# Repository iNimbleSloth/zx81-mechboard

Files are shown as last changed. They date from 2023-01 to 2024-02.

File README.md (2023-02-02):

# ZX81-mechboard
Mechanical keyboard for the ZX81 plus 38 (https://github.com/mahjongg2/ZX81plus38)

This keyboard is designed to use Cherry MX or Gateron switches. <br>
The keyboard is open source, please feel free to modiy it but always link back to this repository.<br>

Watch my video series that features this keyboard on [YouTube](https://www.youtube.com/watch?v=6a8wxj9vJjU&list=PLx7VS_ZJdQyVQSyDkv-Idc9wqWm_9QVhM)<br><br>
KiCAD files_v1.1 - Schematic and PCB layout files for KiCAD<br>
keycaps layout - Keycaps design layout for Adobe Illustrator. Note that if useing wasdkeyboards, then you nned to use the expanded file.<br><br>
Available on [PCBWay Shared Projects](https://www.pcbway.com/project/shareproject/ZX81_Mechanical_Keyboard_68c46a1b.html)<br>

<br><br>
Keycaps printed by wasdkeyboards.com


<br>
Keycaps with sticky labels<br>


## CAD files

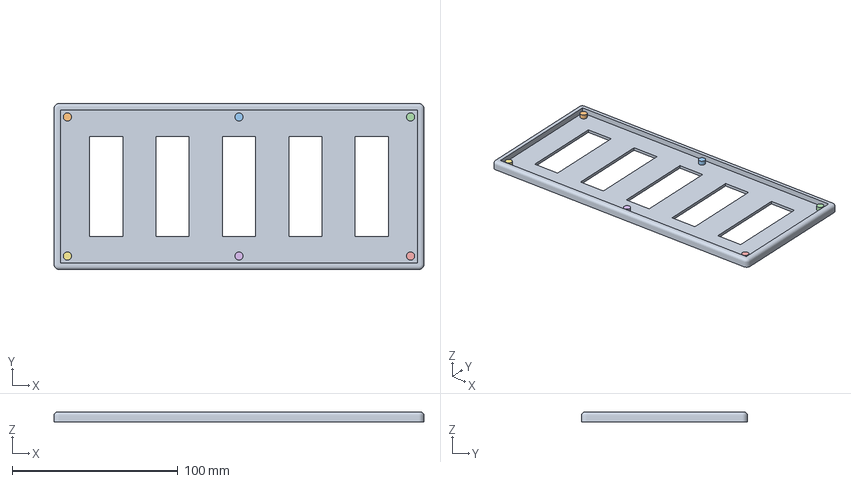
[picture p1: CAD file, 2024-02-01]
keyboard_only_case/ZX81 Keyboard (printed in keyboard video) v54.3mf
223.0 x 100.0 x 6.00 mm

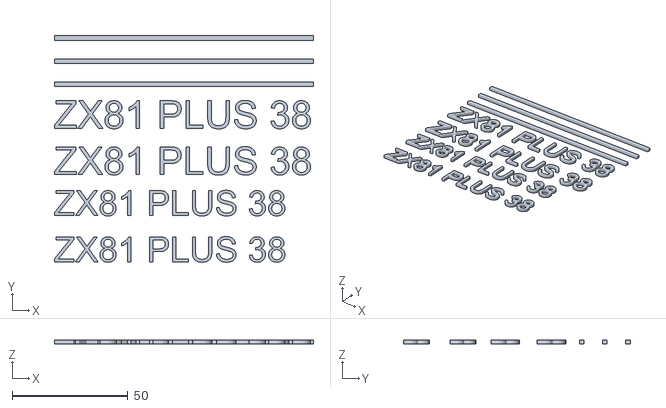
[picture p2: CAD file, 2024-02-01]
ZX81+38 case/ZX81-Text v8.stl
112.0 x 98.0 x 1.60

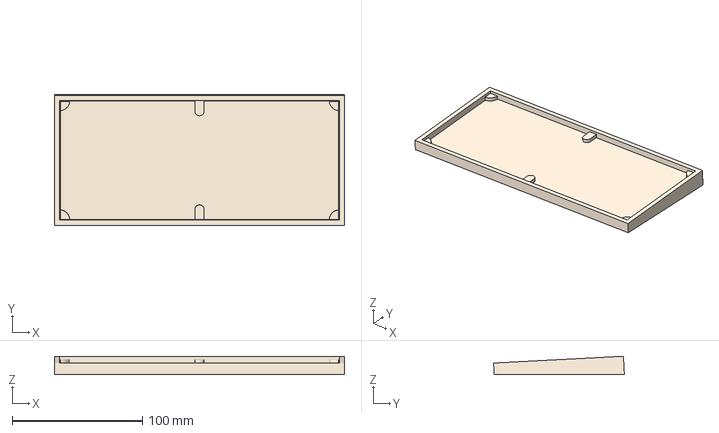
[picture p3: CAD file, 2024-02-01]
keyboard_only_case/ZX81 Keyboard 2 v18.3mf
223.0 x 100.6 x 14.2 mm

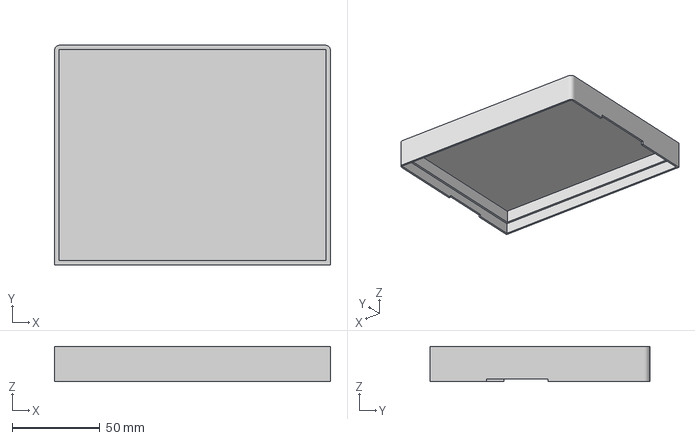
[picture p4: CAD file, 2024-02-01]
ZX81+38 case/ZX81_All-in-one_Top v32.3mf
157.0 x 125.0 x 20.0 mm

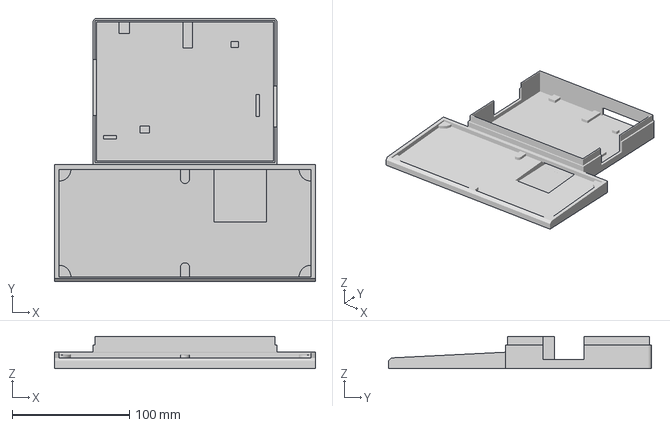
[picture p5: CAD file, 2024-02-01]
ZX81+38 case/ZX81_All-in-one_Base v31.3mf
223.0 x 225.0 x 27.5 mm

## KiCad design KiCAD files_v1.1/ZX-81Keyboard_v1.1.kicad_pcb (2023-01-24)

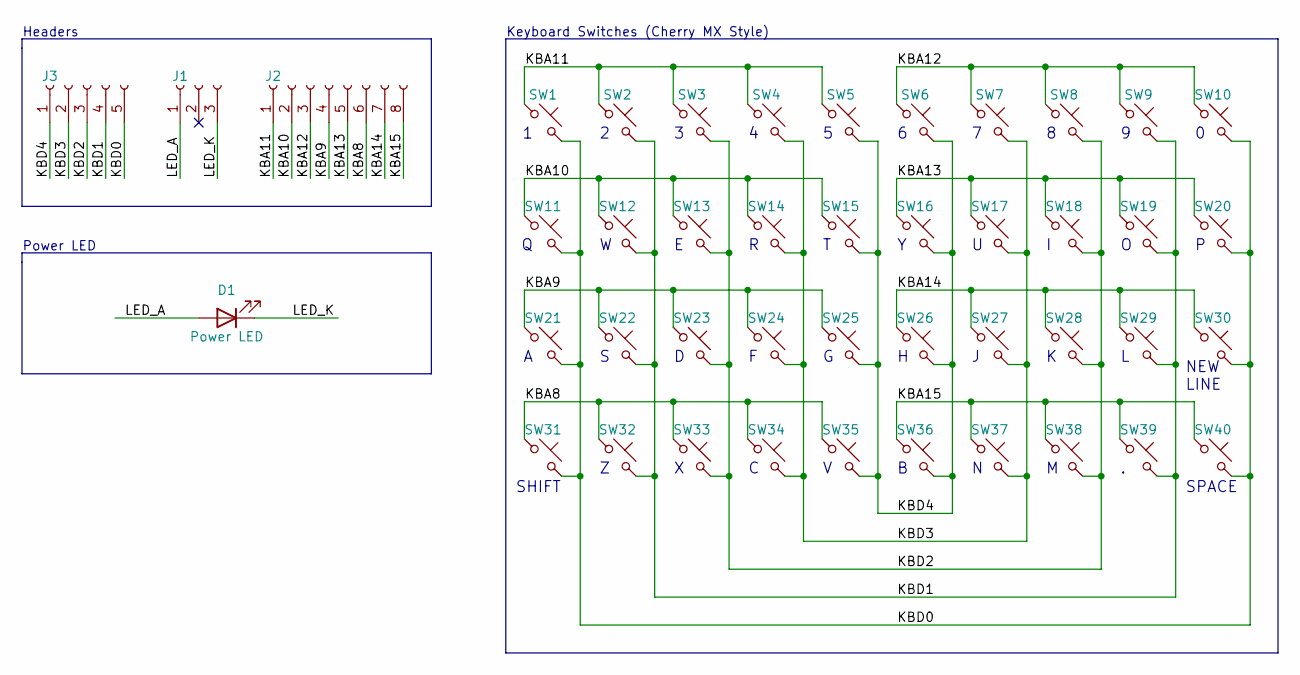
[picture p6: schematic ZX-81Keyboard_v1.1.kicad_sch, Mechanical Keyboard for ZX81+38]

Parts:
D1: Power LED; LED_1206_3216Metric_Pad1.42x1.75mm_HandSolder
J1: Conn_01x03_Female; PinSocket_1x03_P2.54mm_Vertical
J2: Conn_01x08_Female; PinSocket_1x08_P2.54mm_Vertical
J3: Conn_01x05_Female; PinSocket_1x05_P2.54mm_Vertical
SW1: 1; SW_Cherry_MX_1.00u_PCB
SW2: 2; SW_Cherry_MX_1.00u_PCB
SW3: 3; SW_Cherry_MX_1.00u_PCB
SW4: 4; SW_Cherry_MX_1.00u_PCB
SW5: 5; SW_Cherry_MX_1.00u_PCB
SW6: 6; SW_Cherry_MX_1.00u_PCB
SW7: 7; SW_Cherry_MX_1.00u_PCB
SW8: 8; SW_Cherry_MX_1.00u_PCB
SW9: 9; SW_Cherry_MX_1.00u_PCB
SW10: 0; SW_Cherry_MX_1.00u_PCB
SW11: Q; SW_Cherry_MX_1.00u_PCB
SW12: W; SW_Cherry_MX_1.00u_PCB
SW13: E; SW_Cherry_MX_1.00u_PCB
SW14: R; SW_Cherry_MX_1.00u_PCB
SW15: T; SW_Cherry_MX_1.00u_PCB
SW16: Y; SW_Cherry_MX_1.00u_PCB
SW17: U; SW_Cherry_MX_1.00u_PCB
SW18: I; SW_Cherry_MX_1.00u_PCB
SW19: O; SW_Cherry_MX_1.00u_PCB
SW20: P; SW_Cherry_MX_1.00u_PCB
SW21: A; SW_Cherry_MX_1.00u_PCB
SW22: S; SW_Cherry_MX_1.00u_PCB
SW23: D; SW_Cherry_MX_1.00u_PCB
SW24: F; SW_Cherry_MX_1.00u_PCB
SW25: G; SW_Cherry_MX_1.00u_PCB
SW26: H; SW_Cherry_MX_1.00u_PCB
SW27: J; SW_Cherry_MX_1.00u_PCB
SW28: K; SW_Cherry_MX_1.00u_PCB
SW29: L; SW_Cherry_MX_1.00u_PCB
SW30: NEW LINE; SW_Cherry_MX_1.00u_PCB
SW31: SHIFT; SW_Cherry_MX_1.00u_PCB
SW32: Z; SW_Cherry_MX_1.00u_PCB
SW33: X; SW_Cherry_MX_1.00u_PCB
SW34: C; SW_Cherry_MX_1.00u_PCB
SW35: V; SW_Cherry_MX_1.00u_PCB
SW36: B; SW_Cherry_MX_1.00u_PCB
SW37: N; SW_Cherry_MX_1.00u_PCB
SW38: M; SW_Cherry_MX_1.00u_PCB
SW39: .; SW_Cherry_MX_1.00u_PCB
SW40: SPACE; SW_Cherry_MX_1.00u_PCB

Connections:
/KBA8: J2.6, SW31.1, SW32.1, SW33.1, SW34.1, SW35.1
/KBA9: J2.4, SW21.1, SW22.1, SW23.1, SW24.1, SW25.1
/KBA10: J2.2, SW11.1, SW12.1, SW13.1, SW14.1, SW15.1
/KBA11: J2.1, SW1.1, SW2.1, SW3.1, SW4.1, SW5.1
/KBA12: J2.3, SW6.1, SW7.1, SW8.1, SW9.1, SW10.1
/KBA13: J2.5, SW16.1, SW17.1, SW18.1, SW19.1, SW20.1
/KBA14: J2.7, SW26.1, SW27.1, SW28.1, SW29.1, SW30.1
/KBA15: J2.8, SW36.1, SW37.1, SW38.1, SW39.1, SW40.1
/KBD0: J3.5, SW1.2, SW10.2, SW11.2, SW20.2, SW21.2, SW30.2, SW31.2, SW40.2
/KBD1: J3.4, SW2.2, SW9.2, SW12.2, SW19.2, SW22.2, SW29.2, SW32.2, SW39.2
/KBD2: J3.3, SW3.2, SW8.2, SW13.2, SW18.2, SW23.2, SW28.2, SW33.2, SW38.2
/KBD3: J3.2, SW4.2, SW7.2, SW14.2, SW17.2, SW24.2, SW27.2, SW34.2, SW37.2
/KBD4: J3.1, SW5.2, SW6.2, SW15.2, SW16.2, SW25.2, SW26.2, SW35.2, SW36.2
/LED_A: D1.2 (A), J1.1
/LED_K: D1.1 (K), J1.3

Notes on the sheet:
SPACE
Headers
SHIFT
Power LED
NEW LINE
Keyboard Switches (Cherry MX Style)

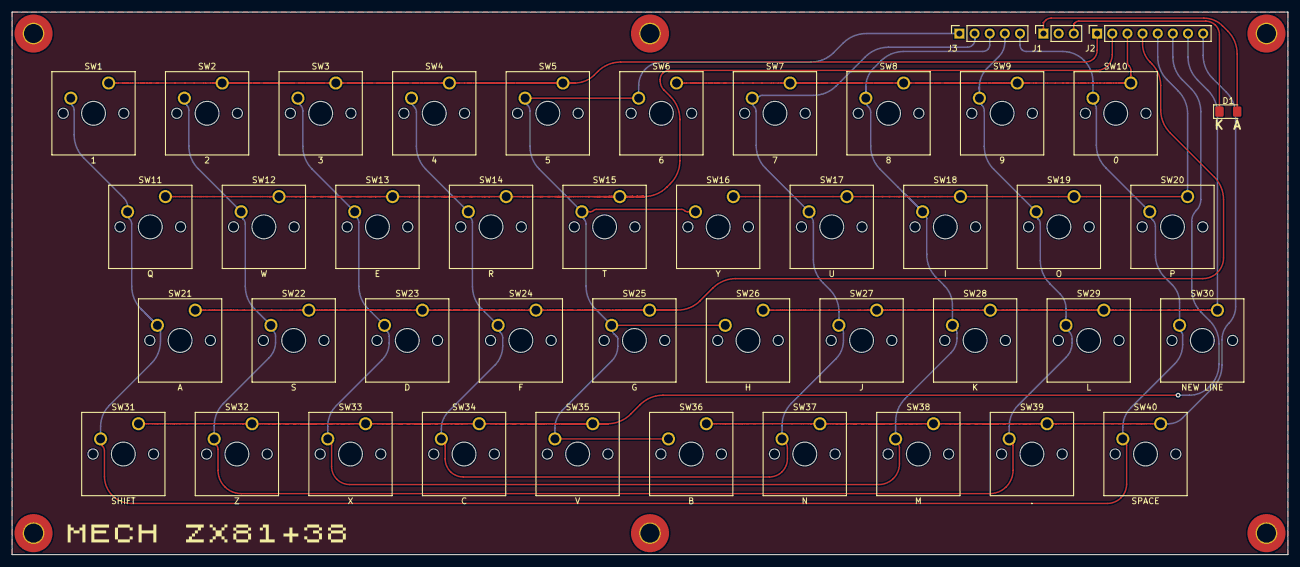
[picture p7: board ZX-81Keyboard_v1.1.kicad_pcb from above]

Board: 2 copper layers, 214.0 x 91.0 mm, 44 parts (0 on the bottom side), 15 nets.

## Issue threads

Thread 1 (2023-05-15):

Keyboard switches

ghhann, 2023-05-15:
I ordered your board off of pcbway.  I was looking for specifics on the switches you used?  Is there an Amazon link you could share?  Also is there a part number for the led?

Best

iNimbleSloth, 2023-05-16:
Hi,
Sure, I used these from Amazon - https://www.amazon.co.uk/gp/product/B09WVWZG8F
Gateron ks-9 G PRO Brown. The LED is any SMD size 1206, . I've used these https://www.amazon.co.uk/gp/product/B09VBR4MLC
The resistor for the LED is on the main ZX81+38 motherboard, just be mindful of that if you are not using that motherboard.

ghhann, 2023-05-16:
Thank you very much.  I'll be doing this project while recovering from a neurological procedure.  Just to confirm for wasd I use the extended keycap file?   Have you ever thought of doing your keycaps for a spectrum?  I would guess that your keyboard is similar that it could work in a spectrum clone board.  Best

iNimbleSloth, 2023-05-18:
[These are the keycaps that I ordered from WASD](https://www.wasdkeyboards.com/62-key-iso-custom-cherry-mx-keycap-set.html).  There is also this [US ANSI version ](https://www.wasdkeyboards.com/61-key-custom-cherry-mx-keycap-set.html).
I ordered the ISO version as I wanted to use some of the "spare" keys for another project requiring the ISO Enter key.

I got the bank template from them at https://support.wasdkeyboards.com/hc/en-us/articles/115007847008-Download-Template-Files. The template I downloaded was the the [62-Key Intl ISO Layout ](https://support.wasdkeyboards.com/hc/article_attachments/4418291821463/wasd-ai-62-08.20.2021.ai), so not the extended file, just the 62 key version.

[My edited keycap file ](https://github.com/iNimbleSloth/zx81-mechboard/tree/main/keycaps%20layout) has two versions, one that has editable text and the other with "Expanded" in the name is no longer "text", its been converted to graphics as that's what WASD request before uploading the file. I placed both files on Github to give the choice of easily editing the raw text if someone wanted, or just going with the expanded to graphics version.

I've not checked the pinouts of the ZX81 vs ZX Spectrum for the keyboard connections, so don't know if compatible.

I hadn't considered doing a ZX Spectrum clone with mechanical keyboard, but that would be quite fun I think.

Hope you recover from your procedure soon!

Closed 2023-05-18.
